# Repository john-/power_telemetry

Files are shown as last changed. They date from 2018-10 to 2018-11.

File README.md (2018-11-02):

Device that converts 12v to 5v, measures power/other things, and controls 4-wire fans.

# DESIGN NOTES

The 3rd 5V converter powers ICs and is a backup

**Power Sensing**

_Calibration_

V bus max   = 16V
V shunt max = 320㎷ (PGA = ÷8)
R shunt     = 0.1Ω

I max possible = V shunt max ÷ R shunt = 3.2A

I max expected = 3A (this needs to be revisited with better understanding of what it represents)

_Serial Bus Address_

Ground A0 and A1 to get adress of 1000000.

I²C bus pull-up resistors of 4.7KΩ was not calculated.  It was from arbitrary site.   The INA219 datasheet references 3.3KΩ.

_Optional Filter_

As filtering may not be needed initial implementation will be 0Ω resistors (R6/7) and capacitor (C3) unpopulated.

_Bypass Capacitors_

Values are taken from datasheet.  Ceramic type chosen from arbitrary page.

Design mistakes:

- I did not include any temp sensors! Now when I read the data sheet for the ADT7470 it makes it clear it is can't do standalone temperature measuring. I previously assumed it had one built-in temperature sensor. Anyway, I will use manual control of the ADT7470 based on temperature of SBCs (there will be 2 Odroid C2s in the case). I may add an external temperature sensor for the temperature sensor. Previously I have used 1 wire sensor. I need to confirm I can use 1 wire and I2C at same time on C2.
- The circuit puts out 5V I2C and the C2 max input voltage 3.3V. I happen to have a level shifter to get things working. I should have had the circuit output 3.3V I2C.
- I am pretty sure I should have included GND with the SDA/SCL lines. Since I had to use the level shifter I wound up pulling in 5V/GND from elsewhere in the circuit.

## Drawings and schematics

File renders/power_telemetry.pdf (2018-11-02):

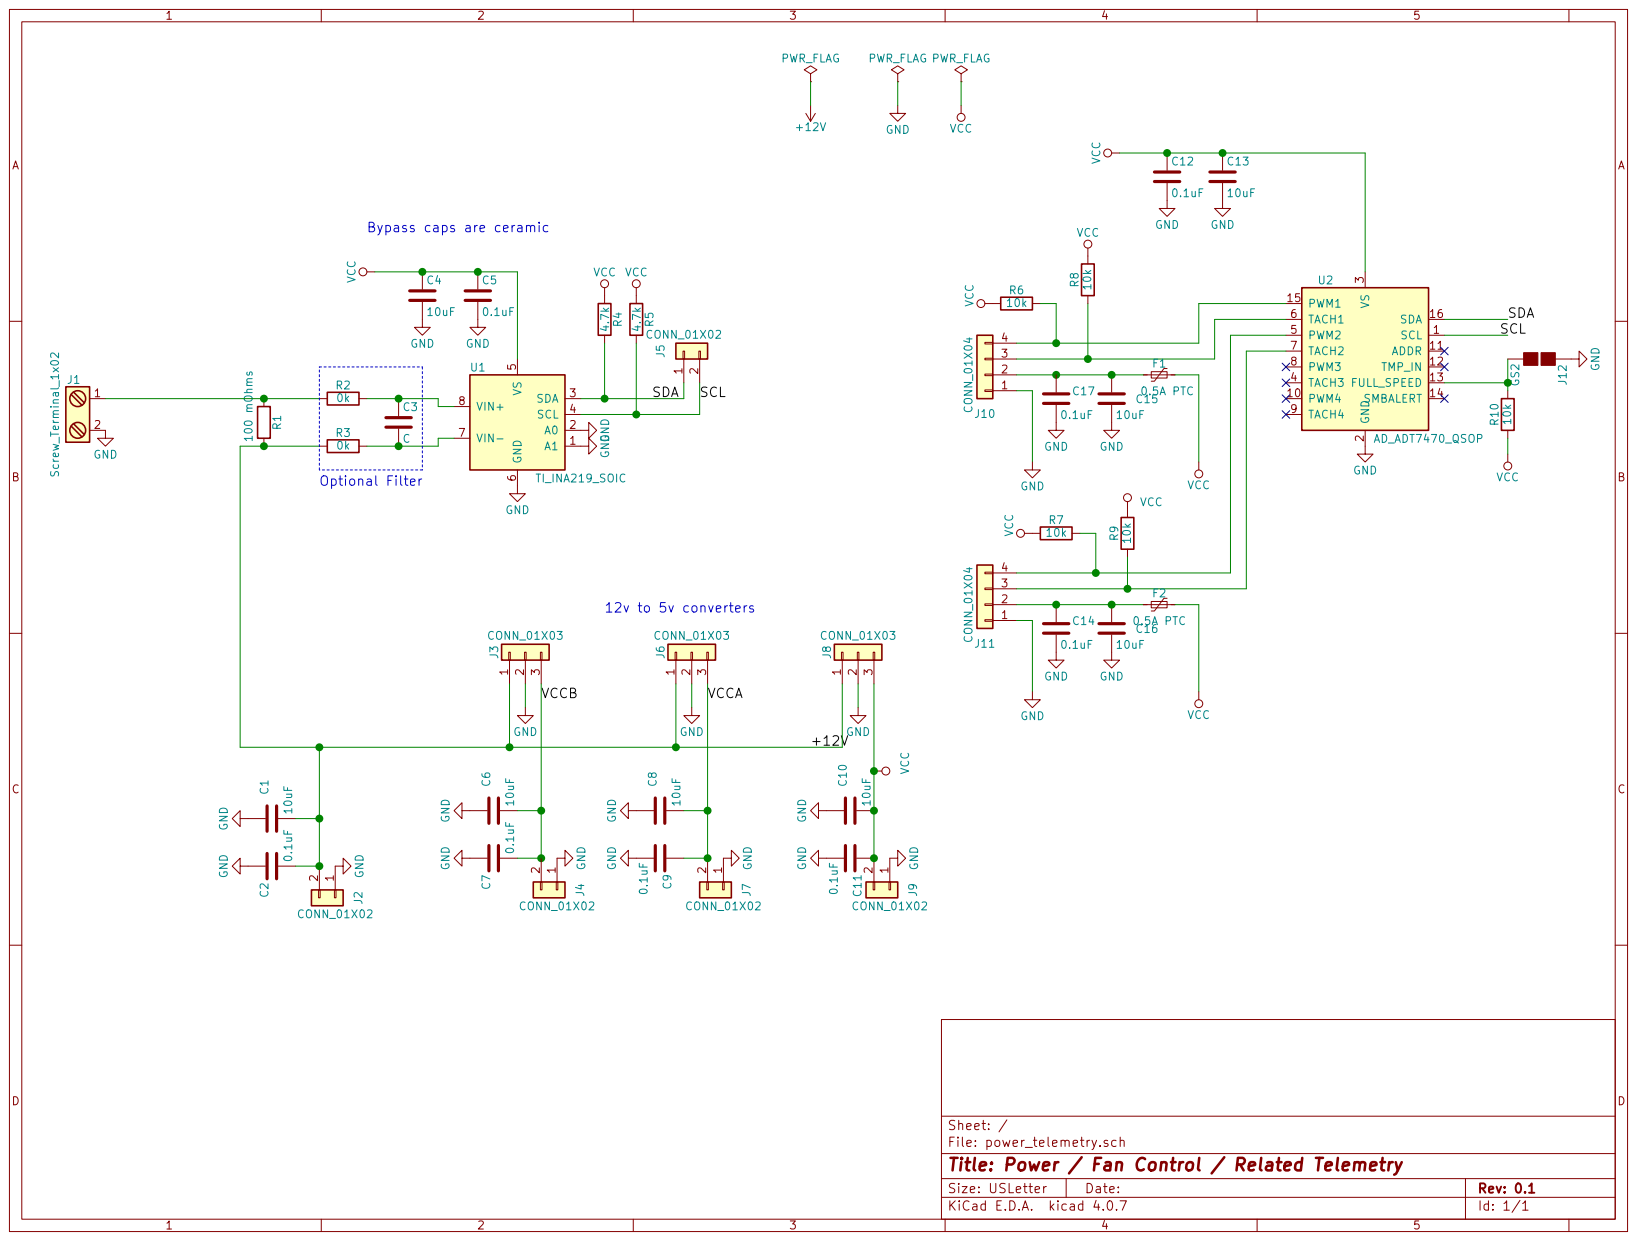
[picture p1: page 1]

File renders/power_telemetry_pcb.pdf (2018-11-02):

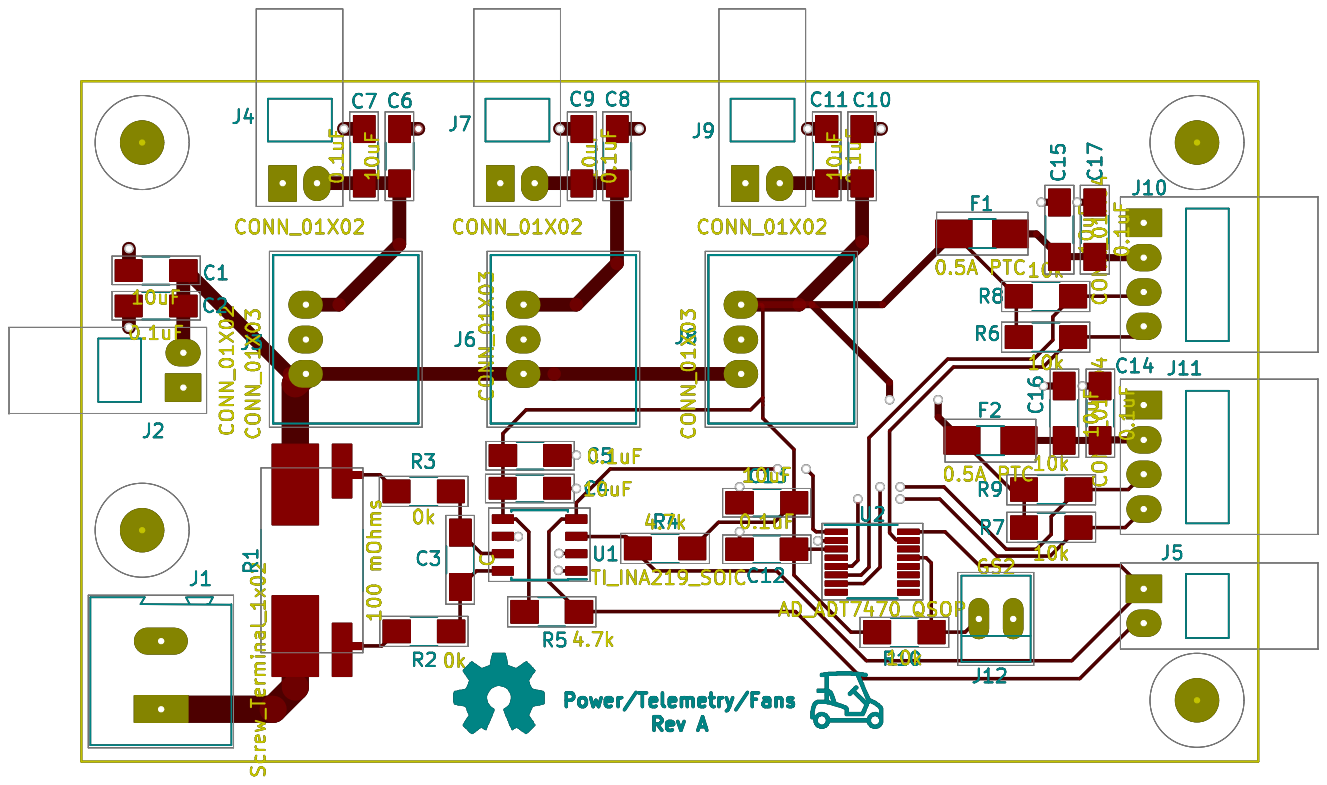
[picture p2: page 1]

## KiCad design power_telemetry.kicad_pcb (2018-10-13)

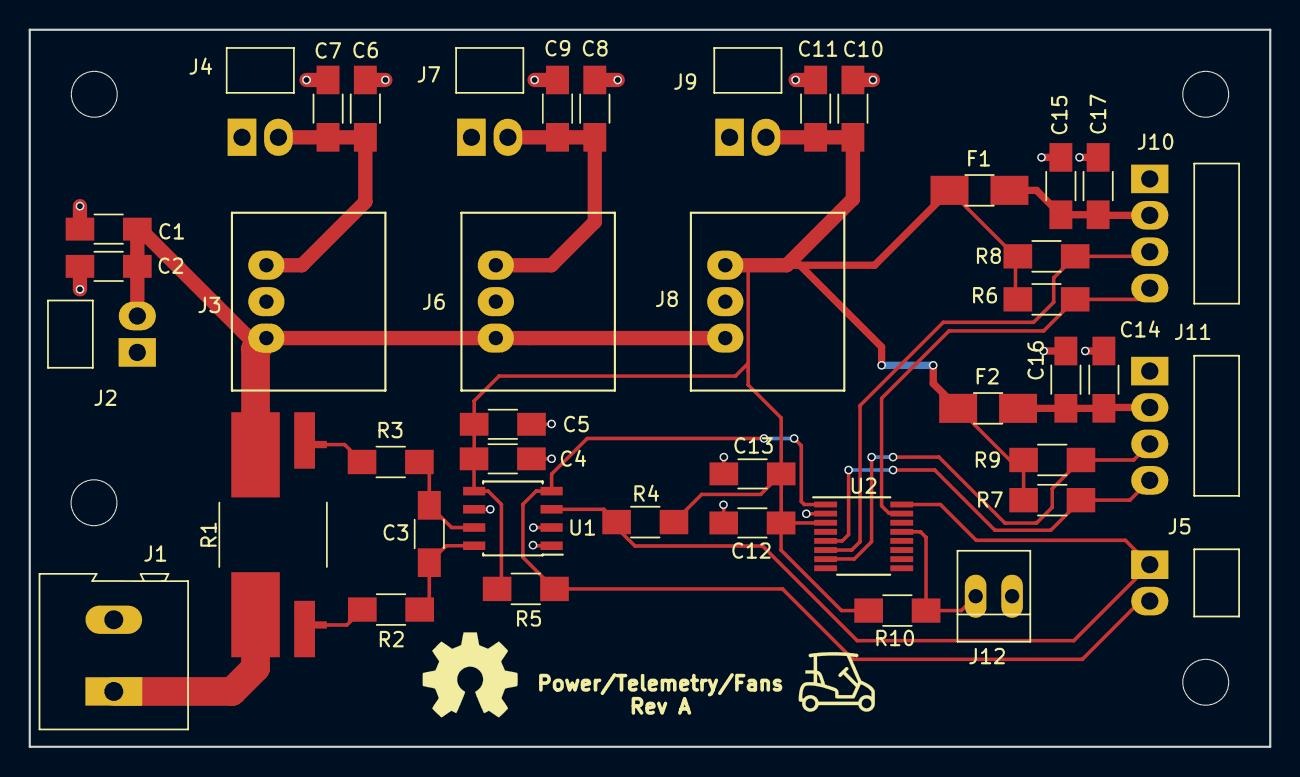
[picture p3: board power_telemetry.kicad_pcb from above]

Board: 2 copper layers, 86.5 x 50.0 mm, 43 parts (0 on the bottom side), 17 nets.

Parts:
C1, C4, C6, C8, C10, C13, C15, C16: 10uF; C_1206_HandSoldering
C2, C5, C7, C9, C11, C12, C14, C17: 0.1uF; C_1206_HandSoldering
C3: C; C_1206_HandSoldering
F1, F2: 0.5A PTC; Fuse_SMD1206_HandSoldering
J1: Screw_Terminal_1x02; TER-202
J2, J4, J5, J7, J9: CONN_01X02; Molex_KK-171857-02x2.54mm_Right
J3, J6, J8: CONN_01X03; DCDC-Conv_Murata_OKI-78SR-E
J10, J11: CONN_01X04; Molex_KK-171857-04x2.54mm_Right
J12: GS2; PINHEAD1-2
R1: 100 mOhms; R_4527_Kelvin2_HandSoldering
R2, R3: 0k; R_1206_HandSoldering
R4, R5: 4.7k; R_1206_HandSoldering
R6, R7, R8, R9, R10: 10k; R_1206_HandSoldering
U1: TI_INA219_SOIC; SOIC-8_3.9x4.9mm_Pitch1.27mm
U2: AD_ADT7470_QSOP; QSOP-16_3.9x4.9mm_Pitch0.635mm

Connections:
+12V: C1.2, C2.2, J2.2, J3.1, J6.1, J8.1, R1.2, R3.1
/SCL: J5.2, R5.2, U1.4, U2.1
/SDA: J5.1, R4.2, U1.3, U2.16
/VCCA: C8.2, C9.1, J6.3, J7.2
/VCCB: C6.2, C7.2, J3.3, J4.2
GND: C1.1, C2.1, C4.2, C5.2, C6.1, C7.1, C8.1, C9.2, C10.1, C11.2, C12.2, C13.2, C14.2, C15.2, C16.2, C17.2, J1.2, J2.1, J3.2, J4.1, J6.2, J7.1, J8.2, J9.1, J10.1, J11.1, J12.1, U1.1, U1.2, U1.6, U2.2
unnamed: C3.1, R2.2, U1.8
unnamed: C3.2, R3.2, U1.7
unnamed: C14.1, C16.1, F2.2, J11.2
unnamed: C15.1, C17.1, F1.2, J10.2
unnamed: J1.1, R1.1, R2.1
unnamed: J10.3, R8.1, U2.6
unnamed: J10.4, R6.2, U2.15
unnamed: J11.3, R9.1, U2.7
unnamed: J11.4, R7.2, U2.5
unnamed: J12.2, R10.2, U2.13
VCC: C4.1, C5.1, C10.2, C11.1, C12.1, C13.1, F1.1, F2.1, J8.3, J9.2, R4.1, R5.1, R6.1, R7.1, R8.2, R9.2, R10.1, U1.5, U2.3

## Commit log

2017-10-15 early stages
    [power_telemetry.kicad_pcb, power_telemetry.sch]
2017-10-15 add a render of schematic
    [power_telemetry.sch]
2017-10-17 more pcb latyout
    [power_telemetry.kicad_pcb, power_telemetry.sch]
2017-10-17 add pcb render
2018-01-27 some changes
    [power_telemetry.kicad_pcb]
2018-02-27 using 5v fan, added graphics
    [power_telemetry.kicad_pcb, power_telemetry.sch]
2018-03-03 switched power connectors
    [power_telemetry.kicad_pcb, power_telemetry.sch]
2018-09-15 define some parts and switch to 4 pad shunt resistor
    [power_telemetry.kicad_pcb, power_telemetry.sch]
2018-09-16 re-annoted all items and starting routing from scratch again
    [power_telemetry.kicad_pcb, power_telemetry.sch]
2018-09-20 progress on pcb layout
    [power_telemetry.kicad_pcb, power_telemetry.sch]
2018-09-22 pcb now has all connections made
    [power_telemetry.kicad_pcb]
2018-09-22 fixed order of power supplies
    [power_telemetry.kicad_pcb, power_telemetry.sch]
2018-10-06 now using correctly sized shunt resistor
    [power_telemetry.kicad_pcb, power_telemetry.sch]
2018-10-06 fixed tracks off sense resistor
    [power_telemetry.kicad_pcb]
2018-10-06 new part for 10uF bypass caps
    [power_telemetry.sch]
2018-10-12 create 4 terminal sense resistor pad layout
2018-10-13 now using 4 pad shunt resistor
    [power_telemetry.kicad_pcb, power_telemetry.sch]
2018-10-13 changed sense resistor to 4527
    [power_telemetry.kicad_pcb, power_telemetry.sch]
2018-10-13 fully switched to another sense resistor
    [power_telemetry.kicad_pcb, power_telemetry.sch]
2018-10-13 updated readme mostly
    [power_telemetry.kicad_pcb]
2018-11-02 added current issues to documentation
